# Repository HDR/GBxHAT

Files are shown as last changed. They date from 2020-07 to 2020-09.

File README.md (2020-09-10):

# GBxHAT

**A GBxCart RW in PiZero Hat format**

Purchase on [OSHPark](https://oshpark.com/shared_projects/nTx9yzmZ)

Uses the original schematic by [InsideGadgets](https://github.com/insidegadgets/GBxCart-RW) with some changes

Uses the Pi Zero HAT template by [Mike Lawrence](https://github.com/mikelawrence/RPi_Zero_pHat_Template)

The CH340 was removed, as TX and RX are connected straight to the pi zero

[Interactive BOM](https://martinrefseth.com/ibom/GBxHat)

**Keep in mind that this is untested and has no software**

## Images

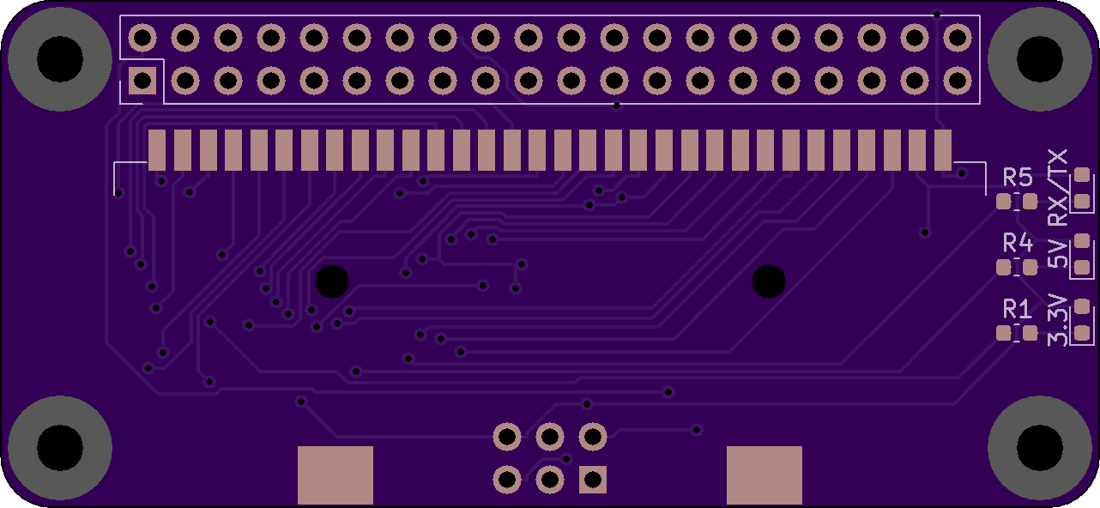
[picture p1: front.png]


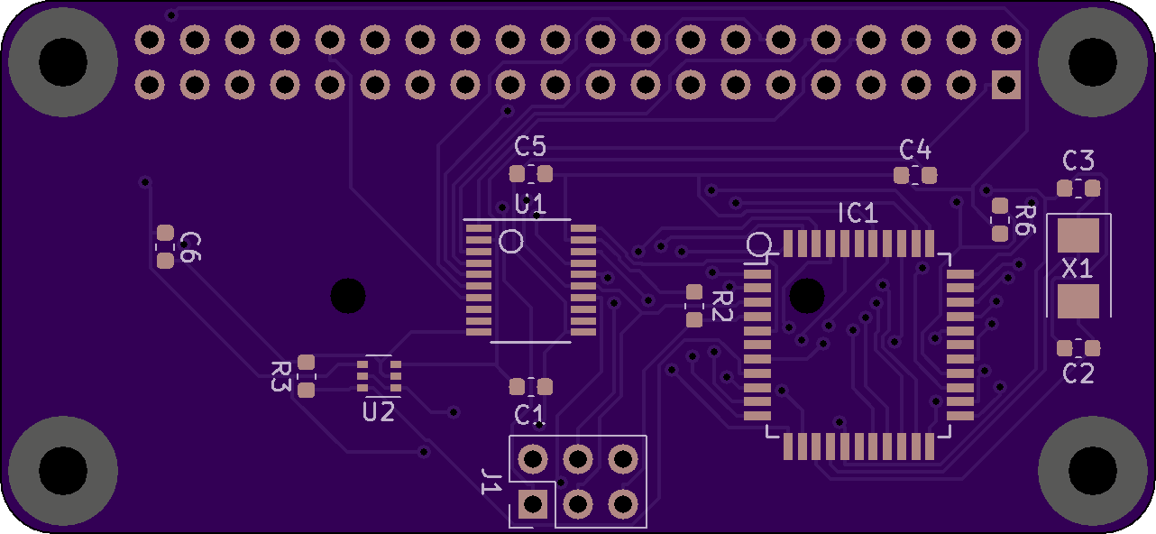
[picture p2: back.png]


## Notes

- Please cut pin 4 on the pi if your hat is not the revision published after July 18th 2020.

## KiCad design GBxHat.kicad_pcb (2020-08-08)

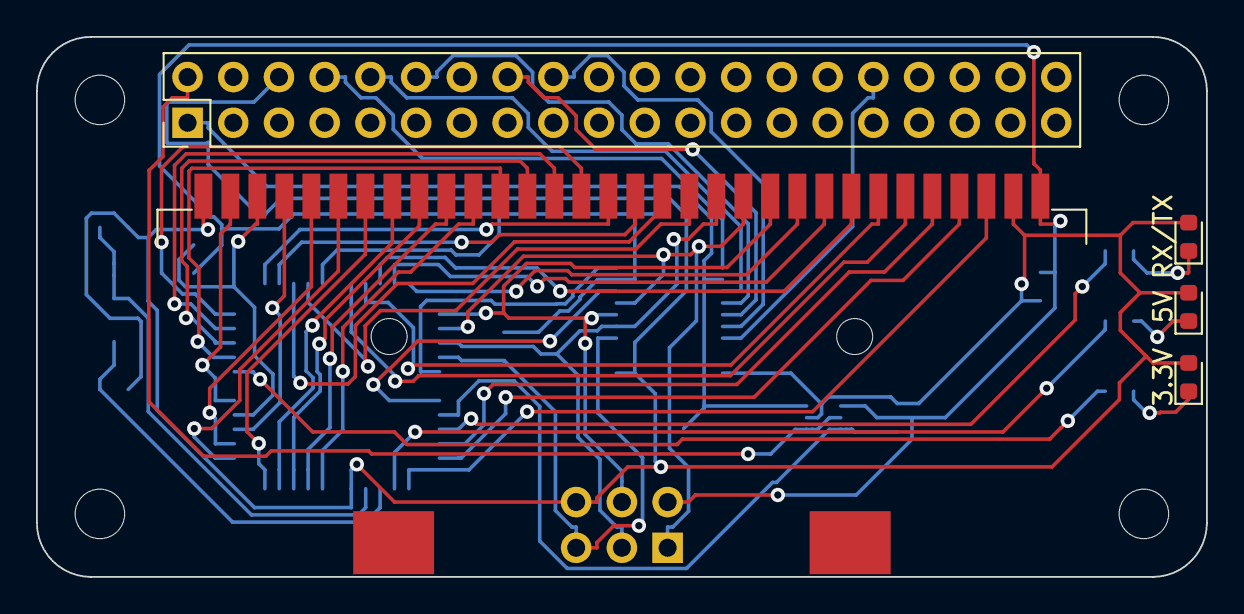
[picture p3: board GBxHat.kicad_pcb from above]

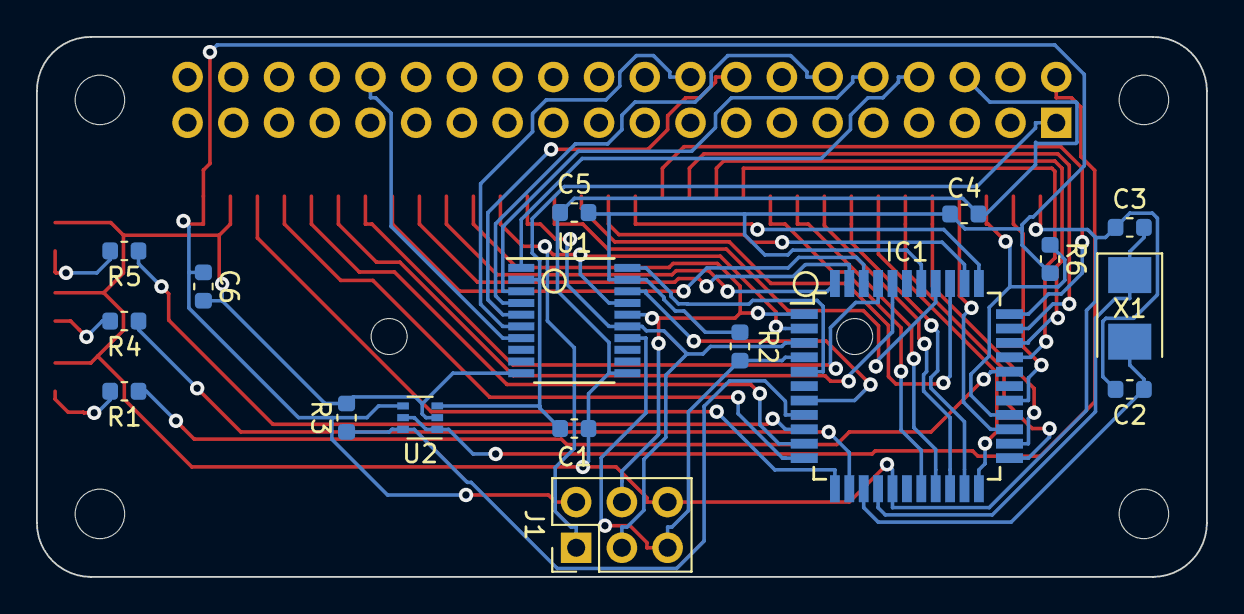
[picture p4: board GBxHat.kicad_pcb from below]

Board: 2 copper layers, 65.0 x 30.0 mm, 26 parts (17 on the bottom side), 51 nets.

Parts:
3.3V: 3.3V LED; LED_0603_1608Metric
5V: 5V LED; LED_0603_1608Metric
C1, C4, C5, C6: 0.1uF; C_0603_1608Metric
C2, C3: 18pF; C_0603_1608Metric
IC1: ATMEGA8515L-8AU; TQFP-44_10x10mm_P0.8mm
J0: Pi Zero; PinHeader_2x20_P2.54mm_Vertical
J1: AVR_SPI_6; PinHeader_2x03_P2.54mm_Vertical
MH1, MH2, MH3, MH4: MountingHole; RPi_Hat_Mounting_Hole
R1, R2, R3, R4, R5, R6: 10K; R_0603_1608Metric
RX/TX: RX/TX LED; LED_0603_1608Metric
U1: TXB0108PWR; TSSOP-20_4.4x6.5mm_P0.65mm
U2: NLAS4157; SOT-363_SC-70-6
U$1: GB_CARTWITH_HOLES; DSL_Cartridge_Reader
X1: 8MHz; Crystal_SMD_5032-2Pin_5.0x3.2mm

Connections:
3.3V: C1.1, J0.1, U1.2, U2.3
5V: J0.2, U2.1, U2.5
/*MREQ/CS: IC1.10, U$1.5
/*RD: IC1.11, U$1.4
/*RESET/CS2: IC1.26, R6.1, U$1.30
/*WR: IC1.12, U$1.3
/A0: IC1.40, U$1.6
/A1: IC1.41, U$1.7
/A2: IC1.42, U$1.8
/A3: IC1.43, U$1.9
/A4: IC1.44, U$1.10
/A5/MOSI: IC1.1, J1.4, U1.16, U$1.11
/A6/MISO: IC1.2, J1.1, U1.17, U$1.12
/A7/SCK: IC1.3, J1.3, U1.15, U$1.13
/A8: IC1.37, U$1.14
/A9: IC1.36, U$1.15
/A10: IC1.35, U$1.16
/A11: IC1.34, U$1.17
/A12: IC1.33, U$1.18
/A13: IC1.32, U$1.19
/A14: IC1.31, U$1.20
/A15: IC1.30, U$1.21
/ATMEGA_RX_OUT: IC1.5, U1.20
/ATMEGA_TX_OUT: IC1.7, U1.18
/AUDIO_IN: IC1.27, U$1.31
/D0: IC1.18, U$1.22
/D1: IC1.19, U$1.23
/D2: IC1.20, U$1.24
/D3: IC1.21, U$1.25
/D4: IC1.22, U$1.26
/D5: IC1.23, U$1.27
/D6: IC1.24, U$1.28
/D7: IC1.25, U$1.29
/PI_MISO: J0.12, U1.4
/PI_MOSI: J0.16, U1.5
/PI_RESET: J0.32, U1.7
/PI_RX_IN: J0.8, U1.1
/PI_SCK: J0.18, U1.6
/PI_TX_IN: J0.10, U1.3
/RESET: IC1.4, J1.5, R2.1, U1.14
/SPDT_SEL: IC1.8, R3.1, U2.6
GND: 3.3V.2, 5V.2, C1.2, C2.2, C3.2, C4.2, C5.2, C6.2, IC1.16, J0.6, J1.6, R3.2, RX/TX.2, U1.10, U1.11, U2.2, U$1.2, U$1.32
unnamed: C2.1, IC1.14, X1.2
unnamed: C3.1, IC1.15, X1.1
unnamed: IC1.9, R5.1
unnamed: IC1.13, R4.1
unnamed: IC1.29, R1.1
unnamed: 3.3V.1, R1.2
unnamed: 5V.1, R4.2
unnamed: R5.2, RX/TX.1
VCC: C4.1, C5.1, C6.1, IC1.38, J1.2, R2.2, R6.2, U1.19, U2.4, U$1.1

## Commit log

2020-07-16 Relocated & Updated LED's
    Changed the identifiers for the LED's to match the GBxCart RW
    Centered LED's on board
    [GBxHat.kicad_pcb]
2020-07-17 Fixed logic level issues & removed voltage regulator
    - Fixed the issue where 5v logic was connected to the Pi zero which is not 5v tolerant
    - Removed the NLAS4157, the 3.3v on the Pi zero itself is now being used instead
    - Removed the 74LVC1G126 chips since RX and TX are now connected to the TXB0108
    [GBxHat.dsn, GBxHat.kicad_pcb, GBxHat.sch]
2020-07-17 Update images and add Gerbers
2020-07-18 Fix an issue where VCC was bound to pin4 on the pi
    [GBxHat.kicad_pcb, GBxHat.sch]
2020-08-06 Moved the LED resistors to the other side of the board as they were in the way of the cart slot
    [GBxHat.kicad_pcb]
2020-08-06 small update
    [GBxHat.kicad_pcb]
2020-08-08 Fix grounding issue and schematic issue
    [GBxHat.kicad_pcb, GBxHat.sch]
